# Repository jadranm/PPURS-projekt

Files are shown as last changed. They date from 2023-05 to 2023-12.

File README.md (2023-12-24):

# PPURS-projekt

CO₂ alarm baziran na ATmega platformi sa Senseair S8 LP senzorom. 
<br>Mikrokontroler ATmega 32 koristeći PWM izlaz senzora s kojima pomoću pinova za vanjske prekide izračunava koncentraciju ugljikovog dioksida u zraku. Uređaj ispisuje izmjerenu koncentraciju CO₂ na vanjskom LCD 16x2 displeju.

Projekt je napravljen za kolegij Projektiranje i primjena ugradbenih računalnih sustava (PPURS).
<br>Programirano u Atmel studiu a PCB je dizajniran u KiCadu.
__________________________________________________________________________________________________________________________________________________________________________

el shema

pcbnew_puXkuX6L0s
pcbnew_Vtx5NFCrFC

    TVZ prijediplomski elektrotehnika / Projektiranje i primjena ugradbenih računalnih sustava 
    [PPURS] 2022/2023 6. semestar

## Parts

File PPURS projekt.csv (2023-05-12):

Id | Designator | Footprint | Quantity | Designation | Supplier and ref
1 | C3,C6,C5,C1,C4,C2 | CP_Radial_Tantal_D5.0mm_P5.00mmjm | 6 | 100nF
2 | D1 | LED_D3.0mm_FlatTop | 1 | LED
3 | Y1 | Crystal_HC49-4H_Vertical | 1 | 8Mhz
4 | Sensair S8 | Senseair_S8_Down | 1 | 004-0-0053
5 | LM35 | TO-92_Inline | 1 | LM35-LP
6 | R1 | R_Axial_DIN0309_L9.0mm_D3.2mm_P12.70mm_Horizontal | 1 | 100k
7 | H2,H4,H1,H3 | MountingHole_2.2mm_M2_DIN965_Pad_TopBottom | 4 | MountingHole
8 | BZ1 | Buzzer_12x9.5RM7.6 | 1 | Buzzer
9 | LCD | PinHeader_2x08_P2.54mm_Verticaljm | 1 | LCD-016N002L
10 | RV1 | Potentiometer_Piher_PT-15-V02_Vertical | 1 | 10k
11 | J3 | BarrelJack_CUI_PJ-063AH_Horizontaljm | 1 | Barrel_Jack
12 | R3,R2 | R_Axial_DIN0309_L9.0mm_D3.2mm_P12.70mm_Horizontal | 2 | 330
13 | SW1,PB0 | SW_PUSH_6mm_H7.3mm | 2 | SW_Push_Dual
14 | L1 | L_Axial_L5.3mm_D2.2mm_P10.16mm_Horizontal_Vishay_IM-1 | 1 | 100uH
15 | ATmega 16A-P | DIP-40_W15.24mm | 1 | ATmega16A-P
16 | PROGRAMATOR | IDC-Header_2x05_P2.54mm_Vertical | 1 | AVR-ISP-10

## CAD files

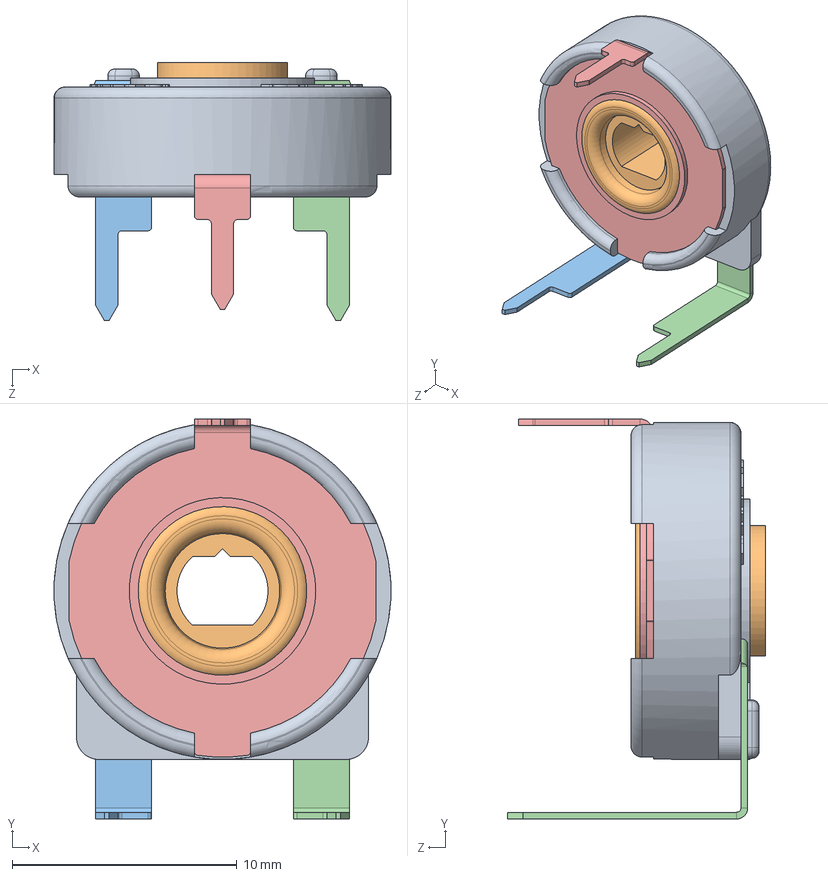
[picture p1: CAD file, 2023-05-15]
3D modeli/20-PIHER_3D_PT15NV17.STEP
15.0 x 17.8 x 11.5 mm
PT15NV17-CARCASA_REMACHADA
PT15NV17-PORTACURSOR_REMACHADO
PT15NV17-TERMINAL DERECHO
PT15NV17-TERMINAL IZQUIERDO
PT15NV17-COLECTOR_PREDETERMINADA

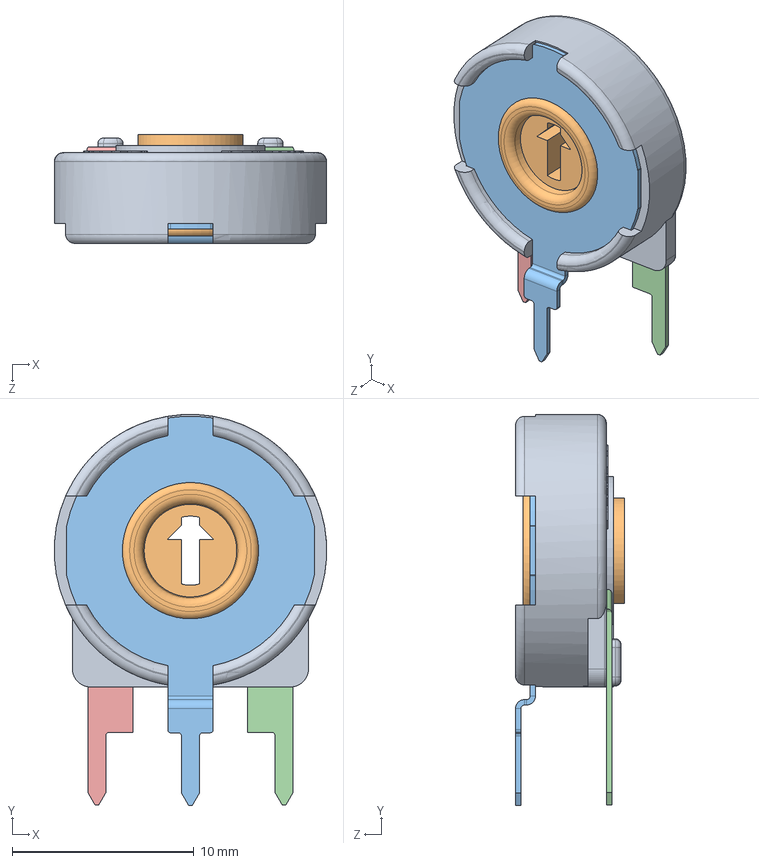
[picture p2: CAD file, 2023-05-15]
3D modeli/21-PIHER_3D_PT15LH05.STEP
15.0 x 21.5 x 6.00 mm
PT15LH05-CARCASA
PT15LH05-PORTACURSOR
PT15LH05-COLECTOR_PREDETERMINADA
PT15LH05-TERMINAL DERECHO
PT15LH05-TERMINAL IZQUIERDO

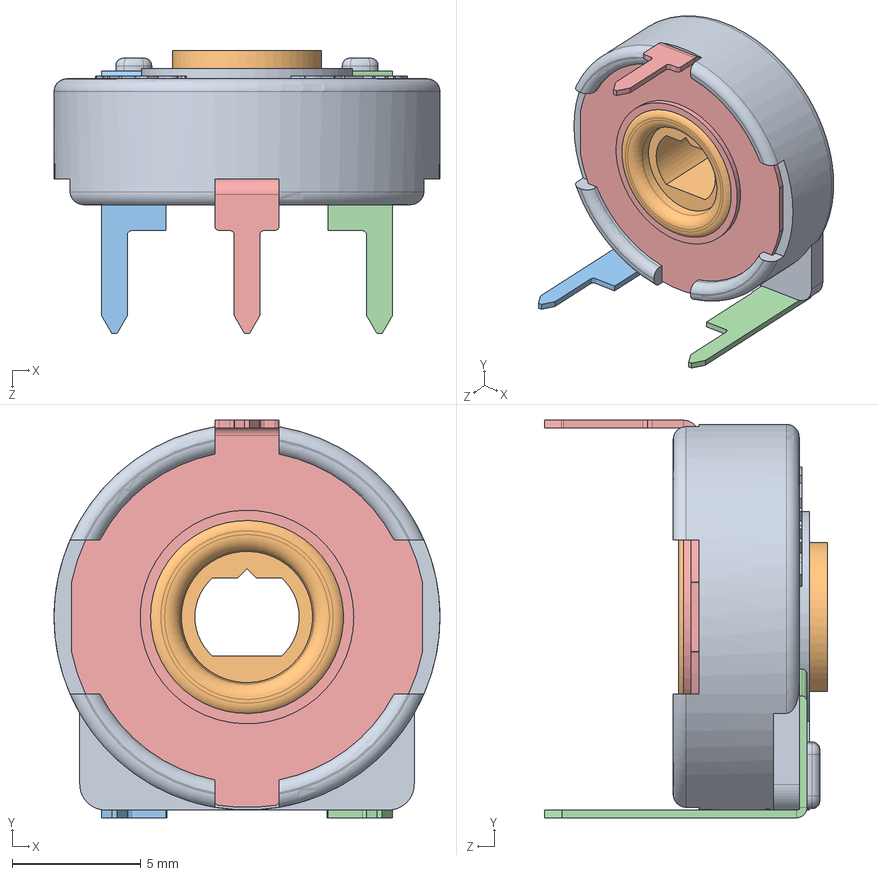
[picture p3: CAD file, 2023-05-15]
3D modeli/19-PIHER_3D_PT15NV15.STEP
15.0 x 15.5 x 11.0 mm
PT15NV15-CARCASA_REMACHADA
PT15NV15-PORTACURSOR_REMACHADO
PT15NV15-TERMINAL DERECHO
PT15NV15-TERMINAL IZQUIERDO
PT15NV15-COLECTOR_PREDETERMINADA

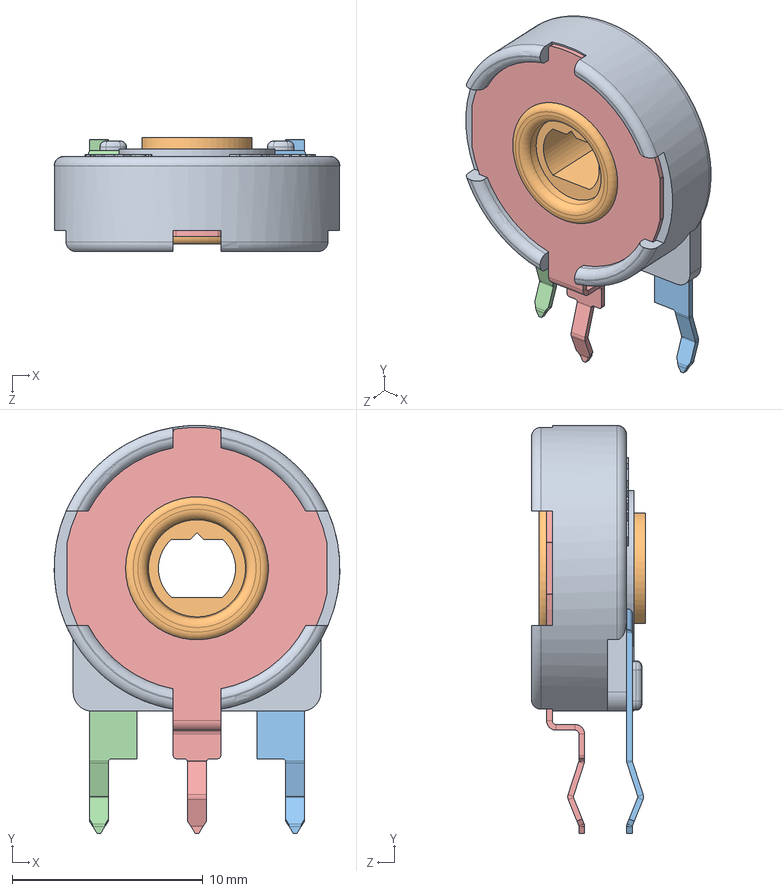
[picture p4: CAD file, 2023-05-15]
3D modeli/18-PIHER_3D_PT15NH02.STEP
15.0 x 21.4 x 6.00 mm
PT15NH02-CARCASA_REMACHADA
PT15NH02-PORTACURSOR
PT15NH02-TERMINAL DERECHO
PT15NH02-TERMINAL IZQUIERDO
PT15NH02-COLECTOR_PREDETERMINADA

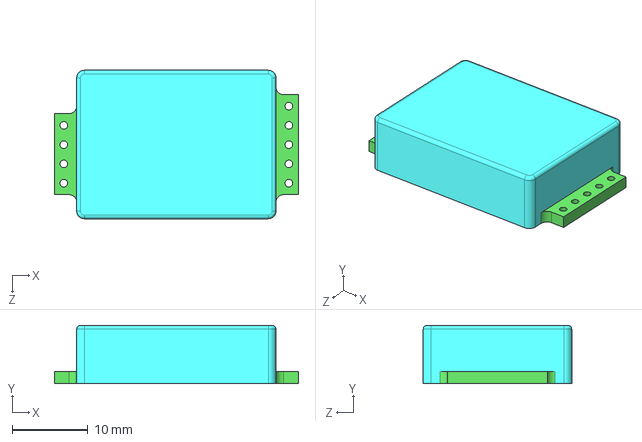
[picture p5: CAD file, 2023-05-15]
3D modeli/User Library-S8-004-0-0053.step
32.2 x 7.70 x 19.6 mm

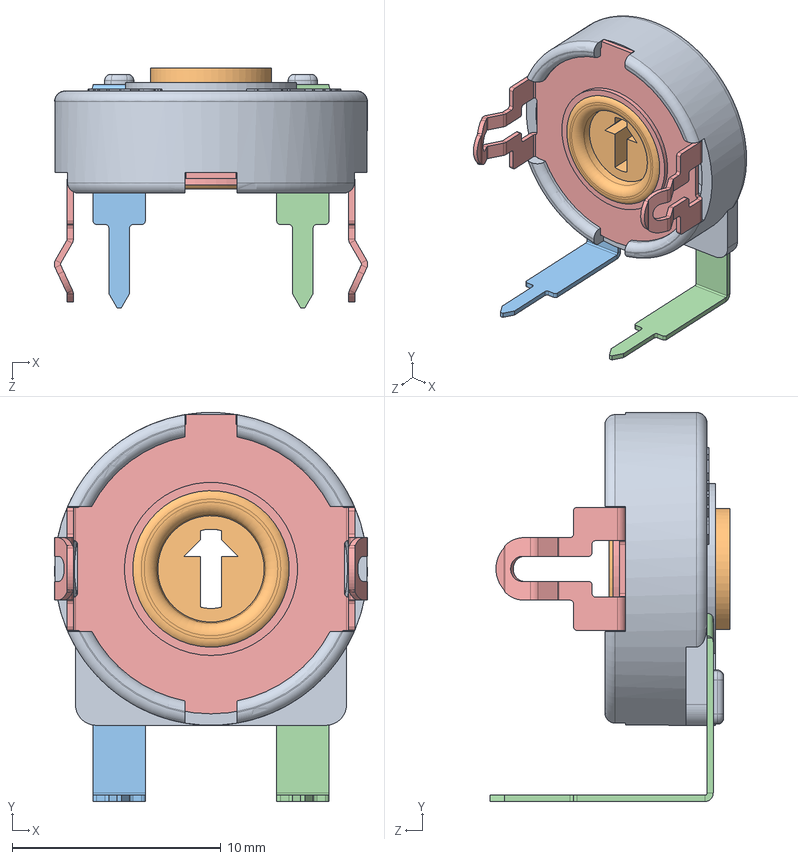
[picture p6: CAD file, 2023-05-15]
3D modeli/PT15LV18.STEP
15.0 x 18.6 x 11.5 mm
PT15LV18-CARCASA_REMACHADA
PT15LV18-PORTACURSOR_REMACHADO
PT15LV18-TERMINAL DERECHO
PT15LV18-TERMINAL IZQUIERDO
PT15LV18-COLECTOR_SUELTO

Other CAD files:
3D modeli/22-PIHER_3D_PT15NV02.STEP

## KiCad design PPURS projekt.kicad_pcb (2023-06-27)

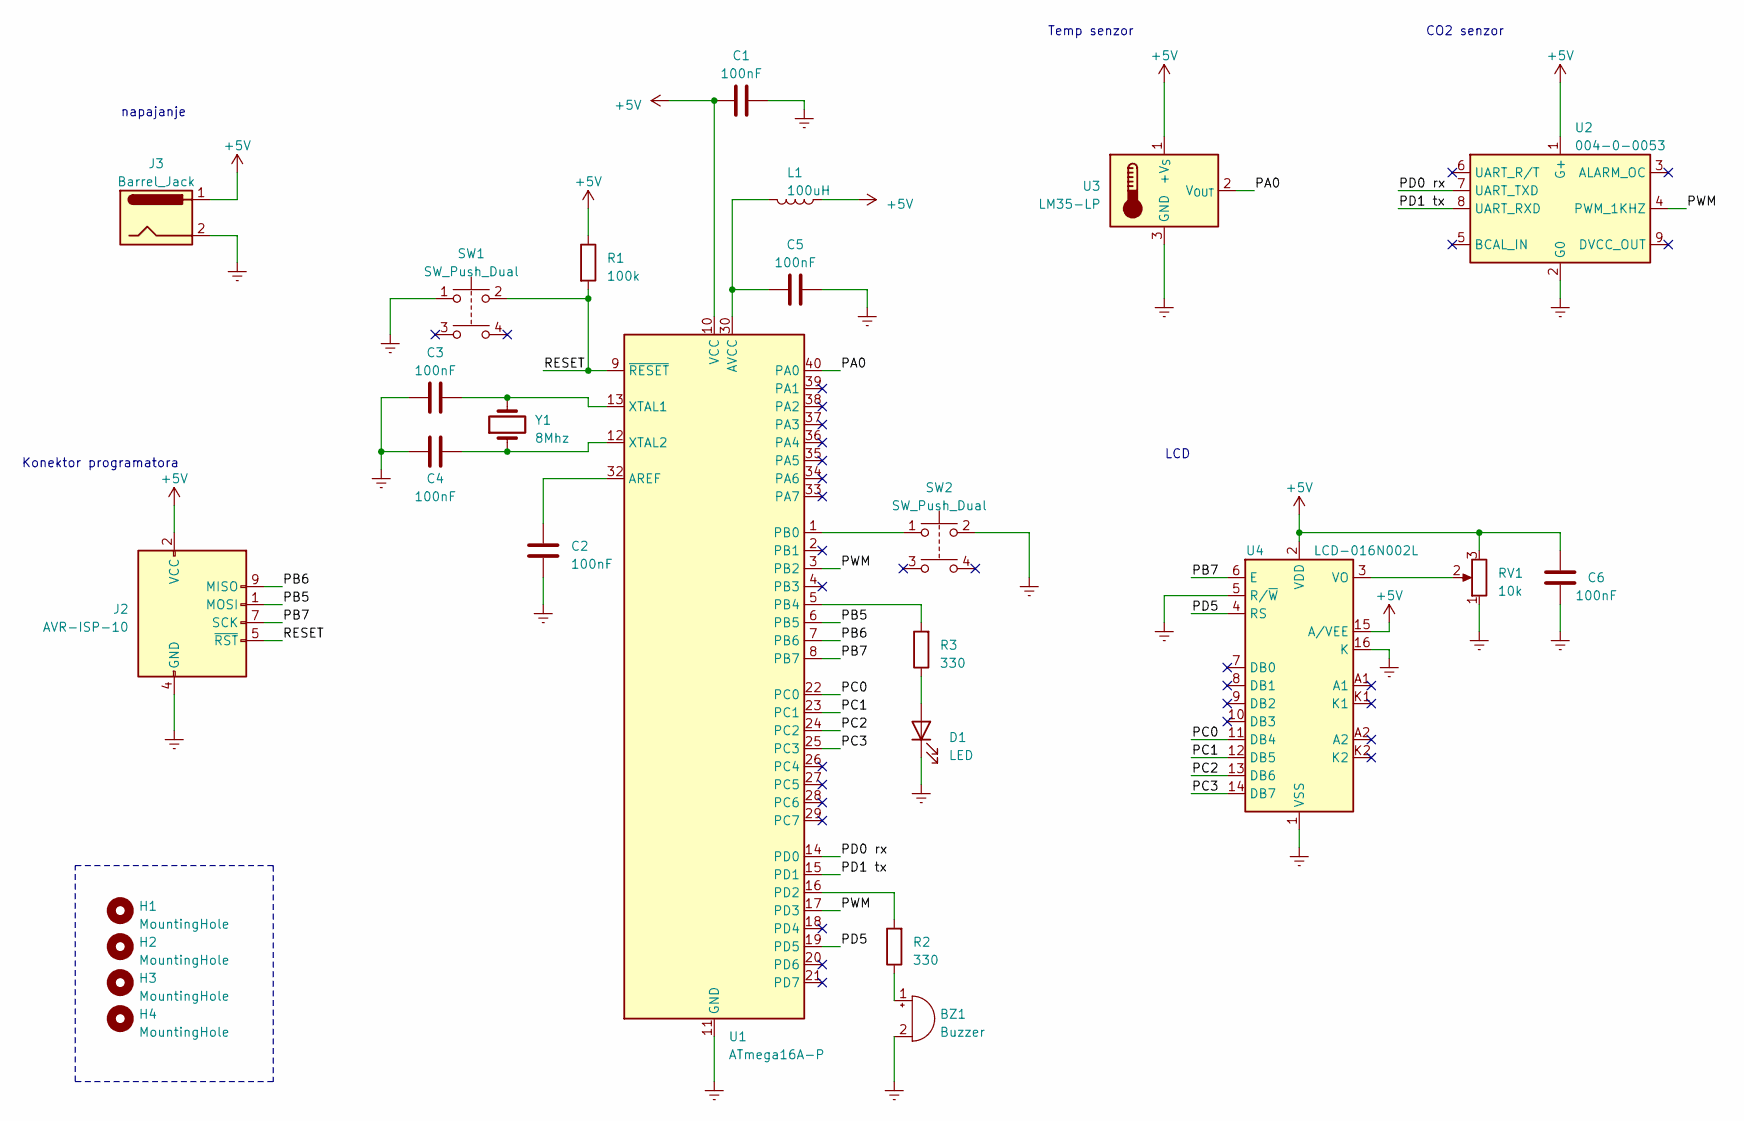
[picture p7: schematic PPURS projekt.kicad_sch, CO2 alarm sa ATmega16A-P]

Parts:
BZ1: Buzzer; Buzzer_12x9.5RM7.6
C1, C2, C3, C4, C5, C6: 100nF; CP_Radial_Tantal_D5.0mm_P5.00mmJM
D1: LED; LED_D5.0mm_Clear
H1, H2, H3, H4: MountingHole; MountingHole_3.2mm_M3_ISO7380_Pad_TopBottom
J2: AVR-ISP-10; IDC-Header_2x05_P2.54mm_Vertical
J3: Barrel_Jack; BarrelJack_CUI_PJ-063AH_HorizontalJM
L1: 100uH; L_Axial_L5.3mm_D2.2mm_P10.16mm_Horizontal_Vishay_IM-1
R1: 100k; R_Axial_DIN0309_L9.0mm_D3.2mm_P12.70mm_Horizontal
R2, R3: 330; R_Axial_DIN0309_L9.0mm_D3.2mm_P12.70mm_Horizontal
RV1: 10k; Potentiometer_Piher_PT-15-V02_Vertical
SW1, SW2: SW_Push_Dual; SW_PUSH_6mm_H7.3mm
U1: ATmega16A-P; DIP-40_W15.24mm
U2: 004-0-0053; Senseair_S8_Down
U3: LM35-LP; TO-92_Inline
U4: LCD-016N002L; PinHeader_2x08_P2.54mm_Verticaljm
Y1: 8Mhz; Crystal_HC49-4H_Vertical

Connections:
+5V: C1.1, C6.1, J2.2 (VCC), J3.1, L1.1, R1.1, RV1.3, U1.10 (VCC), U2.1 (G+), U3.1 (+V_{S}), U4.2 (VDD), U4.15 (A/VEE)
/PA0: U1.40 (PA0), U3.2 (V_{OUT})
/PB5: J2.1 (MOSI), U1.6 (PB5)
/PB6: J2.9 (MISO), U1.7 (PB6)
/PB7: J2.7 (SCK), U1.8 (PB7), U4.6 (E)
/PC0: U1.22 (PC0), U4.11 (DB4)
/PC1: U1.23 (PC1), U4.12 (DB5)
/PC2: U1.24 (PC2), U4.13 (DB6)
/PC3: U1.25 (PC3), U4.14 (DB7)
/PD0 rx: U1.14 (PD0), U2.7 (UART_TXD)
/PD1 tx: U1.15 (PD1), U2.8 (UART_RXD)
/PD5: U1.19 (PD5), U4.4 (RS)
/PWM: U1.3 (PB2), U1.17 (PD3), U2.4 (PWM_1KHZ)
/RESET: J2.5 (~RST), R1.2, SW1.2, U1.9 (~RESET)
Earth: BZ1.2 (+), C1.2, C2.1, C3.2, C4.2, C5.1, C6.2, D1.1 (K), J2.4 (GND), J2.6 (GND), J2.8 (GND), J2.10 (GND), J3.2, RV1.1, SW1.1, SW2.2, U1.11 (GND), U1.31 (GND), U2.2 (G0), U3.3 (GND), U4.1 (VSS), U4.5 (R/~W), U4.16 (K)
unnamed: BZ1.1 (-), R2.1
unnamed: D1.2 (A), R3.1
unnamed: C2.2, U1.32 (AREF)
unnamed: C5.2, L1.2, U1.30 (AVCC)
unnamed: SW2.1, U1.1 (PB0)
unnamed: R3.2, U1.5 (PB4)
unnamed: R2.2, U1.16 (PD2)
unnamed: C3.1, U1.13 (XTAL1), Y1.2
unnamed: C4.1, U1.12 (XTAL2), Y1.1
unnamed: RV1.2, U4.3 (VO)

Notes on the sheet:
CO2 senzor
Temp senzor
LCD
napajanje
Konektor programatora

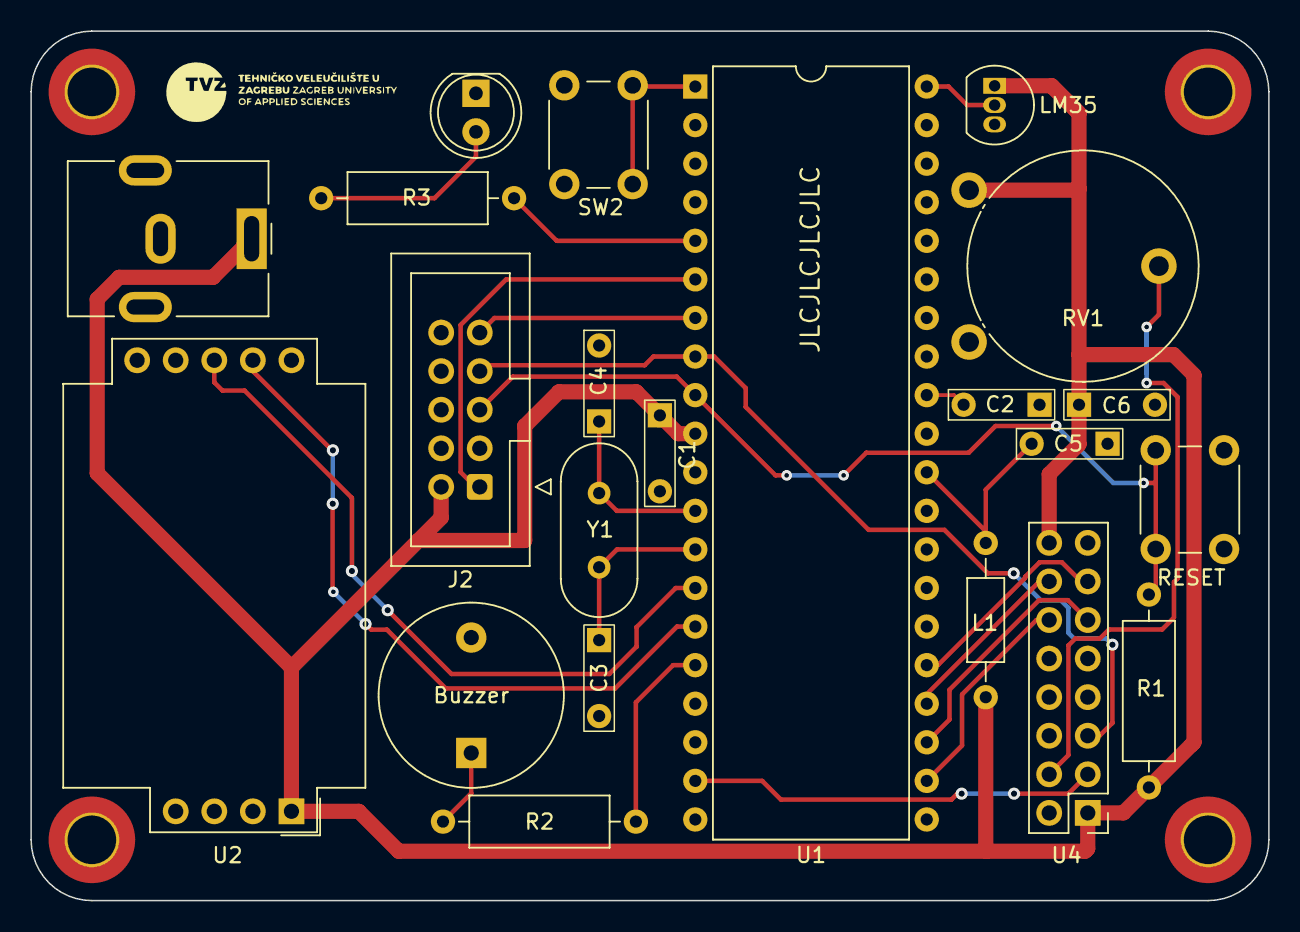
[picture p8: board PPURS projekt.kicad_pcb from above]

Board: 2 copper layers, 81.5 x 57.2 mm, 26 parts (0 on the bottom side), 25 nets.

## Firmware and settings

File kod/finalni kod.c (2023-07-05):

/*
 Autor: Jadran Marinovic
 
 */
#include "AVR lib/AVR_lib.h"
#include "LCD/lcd.h"
#include <avr/io.h>
#include <util/delay.h>
#include "ADC/adc.h"
#include <avr/interrupt.h>
#include "timer/timer.h"
#include <stdbool.h>


#define BROJ_ZUJANJA 2
#define BROJ_UZORKOVANJA 10
#define TEMP_TOLERANCIJA 2	//u postotku


uint16_t duty_duljina;


void alarm(bool buzz){
	uint8_t i;
	
	for (i = 0;i<BROJ_ZUJANJA;i++){
		
		if (buzz == true)
			BUZZ (0.5 , 1000);
		
		PORTB |= 0xF0;
		_delay_ms(500);
		PORTB &= ~0xF0;
		_delay_ms(500);
	}
	return 0;
}

float usrednjavanje(uint8_t pin){
	
	float ADC_zbroj = 0, ADC_prosjek = 0;
	uint8_t i;
	
	for(i = 0; i < BROJ_UZORKOVANJA; i++){		//usrednjavanje rezultata
		ADC = adc_read_10bit(pin);
		ADC_zbroj = ADC_zbroj + ADC;
		_delay_ms(10);
		}
		
	ADC_prosjek = ADC_zbroj / BROJ_UZORKOVANJA;
	return ADC_prosjek;
}


ISR(INT1_vect){		// INT1 rastuci brid
	
	TCNT1 = 0;
}


ISR(INT2_vect){		// INT2 padajuci brid 
	
	duty_duljina = TCNT1;
}


ISR(TIMER1_OVF_vect){  //prekid timera1
	
	lcd_clrscr();
	lcd_home();
	lcd_print("greska pwm-a");
	
	alarm(false);
}


void inicijalizacija(){
	
	lcd_init();
	adc_init();
	sei();
	timer1_init();
	
	
	set_port(PORTB ,PB0 ,1);	//PB0 tipkalo
	output_port(DDRB,PB4);		//PB4 ledica
	
	
	//omoguceni prekidi na INT1 i INT2
	set_bit_reg(GICR ,INT1);
	set_bit_reg(GICR ,INT2); 
	
	
	//INT1 okida na rastuci bit
	set_bit_reg(MCUCR,ISC10); // ISC10 = 1
	set_bit_reg(MCUCR,ISC11); // ISC11 = 1


	//INT2 okida na padajuci bit
	//specijalni slucaj konfiguracije
	reset_bit_reg(MCUCR,ISC2); // ISC2 = 0


	TCNT1=0;
}


int main(void){
	inicijalizacija();
	
		//za ADC
		const float VREF_temp = 5.0;
		float Vout0;
		float Temp, Temp_stara, rezultat0;
		
		//za CO2
		float CO2, duty_cycle, postotak_duty;
		uint8_t brojac_ekrana = 0;
		
		
	while (1){
		
		duty_cycle = duty_duljina * 0.001;
		postotak_duty = (duty_cycle/1.002)*100;  //1.002 je sirina impulsa
		CO2 = 2000 * (postotak_duty/100);
		
		if (CO2>1000){
			alarm(true);
		}
		
		
		if(debounce (&PINB , PB0 , 0) == 0){
			set_port(PORTB , PB0 , 1);
			brojac_ekrana++;
						
			if(brojac_ekrana == 3)
				brojac_ekrana = 0;
				
		}else{
			set_port(PORTB , PB7 , 0);
		}
		
	
		
		if (brojac_ekrana == 0){
			
			lcd_clrscr();
			lcd_home();
			//lcd_print("%0.2f ", postotak_duty);
			lcd_print("CO2:");
			lcd_gotoxy(1,0);
			lcd_print("%0.0f ppm", CO2);
			
			_delay_ms(500);
			
		
		}else if (brojac_ekrana == 1){
			
			//za ADC0 za LM35
			rezultat0 = usrednjavanje(0);

			Vout0 = (rezultat0) * VREF_temp / 1023;
			Temp = Vout0 * 100;
			
				if (Temp_stara > Temp * (1 - (TEMP_TOLERANCIJA/100)) && Temp_stara < Temp * (1 + (TEMP_TOLERANCIJA/100))){
					
					lcd_clrscr();
					lcd_home();
					lcd_print("Temperatura55:");
					lcd_gotoxy(1,0);
					lcd_print("%0.2f%cC", Temp_stara, 178);
					
					_delay_ms(500);
					
				}else{
				
					lcd_clrscr();
					lcd_home();
					lcd_print("Temperatura:");
					lcd_gotoxy(1,0);
					lcd_print("%0.2f%cC", Temp, 178);
					Temp_stara = Temp;
					
					_delay_ms(500);
				}
				
			
			}else if(brojac_ekrana == 2){
				
				lcd_clrscr();
				lcd_home();
				lcd_print("Kvaliteta zraka:");
				//lcd_print("%0.0f ppm", CO2);
				lcd_gotoxy(1,0);
				
				
				if (CO2<600){
					lcd_print("odlicna");
					
				}else if(CO2>601 && CO2<800){
					lcd_print("jako dobra");
					
				}else if(CO2>801 && CO2<1000){
					lcd_print("dobra");
					
				}else if (CO2>1001 && CO2<1500){
					lcd_print("losa");
					
				}else{
					lcd_print("jako losa");
				} 
				
				_delay_ms(300);
			}
	}
	return 0;
}

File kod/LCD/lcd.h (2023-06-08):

/*
 Naslov: MIKRORAÈUNALA - Programiranje mikrokontrolera porodice
 Atmel u programskom okruženju Atmel Studio 6
 Autori: Zoran Vrhovski, Marko Miletiæ
 
 lcd.h
 
 */ 

#include <avr/io.h>
#include <stdio.h>
#include <string.h>
#include <avr/pgmspace.h>
#include <util/delay.h>
#include "../AVR lib/AVR_lib.h"

// konfiguracija LCD displeja
#define LCD_DATA0_PORT   PORTC     	// port za 4 bitnu komunikaciju - podatkovni bit 0 	//D4
#define LCD_DATA1_PORT   PORTC     	// port za 4 bitnu komunikaciju - podatkovni bit 1 	//D5
#define LCD_DATA2_PORT   PORTC     	// port za 4 bitnu komunikaciju - podatkovni bit 2 	//D6
#define LCD_DATA3_PORT   PORTC     	// port za 4 bitnu komunikaciju - podatkovni bit 3 	//D7
#define LCD_DATA0_PIN    PC0          // pin za 4 bitnu komunikaciju - podatkovni bit 0 //D4
#define LCD_DATA1_PIN    PC1          // pin za 4 bitnu komunikaciju - podatkovni bit 1 //D5
#define LCD_DATA2_PIN    PC2          // pin za 4 bitnu komunikaciju - podatkovni bit 2 //D6
#define LCD_DATA3_PIN    PC3          // pin za 4 bitnu komunikaciju - podatkovni bit 3 //D7
#define LCD_RS_PORT      PORTD     	// port za odabir registra //RS
#define LCD_RS_PIN       PD5          // pin  za odabir registra
#define LCD_E_PORT       PORTB    	// port za odobrenje upisa //EN
#define LCD_E_PIN        PB7          // port za odobrenje upisa								//izmjenjeno PD7 na PB7

#define LCD_LINES		2			// broj vidljivih linija na LCD displeju
#define LCD_DISP_LENGTH  16    		// broj vidljivih znakova po liniji na LCD displeju

//#define LCD_RW_PORT      LCD_PORT // port za  èitanje/pisanje - mi samo pišemo //RW
//#define LCD_RW_PIN       5        // pin za  èitanje/pisanje - mi samo pišemo

// kraj konfiguracije LCD displeja




// instruction register bit positions, see HD44780U datasheet
#define LCD_CLR               	0x0    	// DB0: clear display
#define LCD_HOME              	0x1    	// DB1: return to home position
#define LCD_ENTRY_MODE        	0x2     // DB2: set entry mode
#define LCD_ENTRY_INC         	0x1     // DB1: 1=increment, 0=decrement
#define LCD_ENTRY_SHIFT       	0x0     // DB2: 1=display shift on
#define LCD_ON                	0x3     // DB3: turn lcd/cursor on
#define LCD_ON_DISPLAY        	0x2     // DB2: turn display on
#define LCD_ON_CURSOR         	0x1     // DB1: turn cursor on
#define LCD_ON_BLINK          	0x0     // DB0: blinking cursor ?
#define LCD_MOVE              	0x4     // DB4: move cursor/display
#define LCD_MOVE_DISP         	0x3     // DB3: move display (0-> cursor) ?
#define LCD_MOVE_RIGHT        	0x2     // DB2: move right (0-> left) ?
#define LCD_FUNCTION          	0x5     // DB5: function set
#define LCD_FUNCTION_8BIT     	0x4     // DB4: set 8BIT mode (0->4BIT mode)
#define LCD_FUNCTION_2LINES   	0x3     // DB3: two lines (0->one line)
#define LCD_FUNCTION_10DOTS   	0x2     // DB2: 5x10 font (0->5x7 font)
#define LCD_CGRAM             	0x6     // DB6: set CG RAM address
#define LCD_DDRAM             	0x7     // DB7: set DD RAM address
#define LCD_BUSY              	0x7     // DB7: LCD is busy

// set entry mode: display shift on/off, dec/inc cursor move direction
#define LCD_ENTRY_DEC            0x04	// display shift off, dec cursor move dir
#define LCD_ENTRY_DEC_SHIFT      0x05   // display shift on,  dec cursor move dir
#define LCD_ENTRY_INC_           0x06   // display shift off, inc cursor move dir
#define LCD_ENTRY_INC_SHIFT      0x07   // display shift on,  inc cursor move dir

// display on/off, cursor on/off, blinking char at cursor position
#define LCD_DISP_OFF             0x08   // display off
#define LCD_DISP_ON              0x0C   // display on, cursor off
#define LCD_DISP_ON_BLINK        0x0D   // display on, cursor off, blink char
#define LCD_DISP_ON_CURSOR       0x0E   // display on, cursor on
#define LCD_DISP_ON_CURSOR_BLINK 0x0F   // display on, cursor on, blink char

// move cursor/shift display
#define LCD_MOVE_CURSOR_LEFT     0x10   // move cursor left  (decrement)
#define LCD_MOVE_CURSOR_RIGHT    0x14   // move cursor right (increment)
#define LCD_MOVE_DISP_LEFT       0x18   // shift display left
#define LCD_MOVE_DISP_RIGHT      0x1C   // shift display right

// function set: set interface data length and number of display lines
#define LCD_FUNCTION_4BIT_1LINE  0x20   // 4-bit interface, single line, 5x7 dots
#define LCD_FUNCTION_4BIT_2LINES 0x38   // 4-bit interface, dual line,   5x7 dots
#define LCD_FUNCTION_8BIT_1LINE  0x30   // 8-bit interface, single line, 5x7 dots
#define LCD_FUNCTION_8BIT_2LINES 0x38   // 8-bit interface, dual line,   5x7 dots

#define LCD_START_LINE1  		 0x00   // DDRAM address of first char of line 1
#define LCD_START_LINE2  		 0x40   // DDRAM address of first char of line 2
#define LCD_START_LINE3  		 0x14   // DDRAM address of first char of line 3
#define LCD_START_LINE4  		 0x54   // DDRAM address of first char of line 4



// --- LCD Utils
// functional macros
#define lcd_e_delay()   __asm__ __volatile__( "rjmp 1f\n 1:" );
#define lcd_e_high()    LCD_E_PORT  |=  _BV(LCD_E_PIN);
#define lcd_e_low()     LCD_E_PORT  &= ~_BV(LCD_E_PIN);
#define lcd_rs_high()   LCD_RS_PORT |=  _BV(LCD_RS_PIN)
#define lcd_rs_low()    LCD_RS_PORT &= ~_BV(LCD_RS_PIN)
// address of data direction register of port x
#define LCD_DDR(x) 		(*(&x - 1))





// --- Forward functions


//-----------------------------------------------------------------------------------------
// FUNCTION: _auxToggleE
// PURPOSE: flush channel E
void lcd_e_toggle(void);

//-----------------------------------------------------------------------------------------
// FUNCTION: lcd_write
// PURPOSE: send a character or an instruction to the LCD
void lcd_write(uint8_t data,uint8_t rs) ;

//-----------------------------------------------------------------------------------------
// FUNCTION: lcd_instr
// PURPOSE:  send an instruction to the LCD
void lcd_instr(uint8_t instr);

//-----------------------------------------------------------------------------------------
// FUNCTION: lcd_char
// PURPOSE:  send a character to the LCD
void lcd_char(uint8_t data);

//-----------------------------------------------------------------------------------------
// FUNCTION: lcd_init
// PURPOSE:  Initialize LCD to 4 bit I/O mode
void lcd_init();

//-----------------------------------------------------------------------------------------
// FUNCTION: lcd_newline
// PURPOSE:  Move cursor on specified line
void lcd_setline(uint8_t line);

extern int g_nCurrentLine;

//-----------------------------------------------------------------------------------------
// FUNCTION: lcd_print
// PURPOSE:  send a null terminated string to the LCD eg. char x[10]="hello!";
void lcd_print2(char *text);
void lcd_print(char *szFormat, ...);
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

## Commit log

2023-05-12 Add files via upload
    prvi upload
    [PPURS projekt.csv, PPURS projekt.kicad_pcb, PPURS projekt.kicad_sch]
2023-06-09 dodan ADC za LM35
2023-06-27 pwm radi
    [PPURS projekt.kicad_pcb, PPURS projekt.kicad_sch]
